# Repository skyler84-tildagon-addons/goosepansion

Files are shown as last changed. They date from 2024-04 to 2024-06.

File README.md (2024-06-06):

# Goosepansion

*Tildagon Badge Hexpansion by Skyler84*

The **Goosepansion** hexpansion is a capacitive touch addon for the Tildagon badge. Additionally it is designed to be reversible - it can be inserted in either orientation to alter the behaviour of the hexpansion!

## **IMPORTANT**

The hardware of the original Goosepansion had some issues with the active electronics. This is being investigated and a bodge fix will hopefully be released soon!

## Hardware

The goosepansion contains some active electronics that are supposed to allow it to be inserted in either orientation. This is achieved by switching two pairs of pass-fets acting as level shifters and *should* allow the I2C bus to work in either orientation. This had some issues in the original board which is being tested and updated.

### BOM

- 2 * [DMG6602SVTQ-7 complementary PN mosfet pair](https://www.mouser.co.uk/ProductDetail/Diodes-Incorporated/DMG6602SVTQ-7?qs=s5XU71A7K7%252BjMAi7Ml65qw%3D%3D)
- 2 * [DMN63D8LDW-7 dual n-channel mosfet](https://www.mouser.co.uk/ProductDetail/Diodes-Incorporated/DMN63D8LDW-7?qs=wo71MgyKIyE2w30D2buODQ%3D%3D)
- 1 * [M24C64-RDW6TP 8KB I2C EEPROM](https://www.mouser.co.uk/ProductDetail/STMicroelectronics/M24C64-RDW6TP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)
- 2 * 0603 LED
- 2 * current limiting resistors for LEDs
- 5 * 1k resistors
- 1 * 100k resistor

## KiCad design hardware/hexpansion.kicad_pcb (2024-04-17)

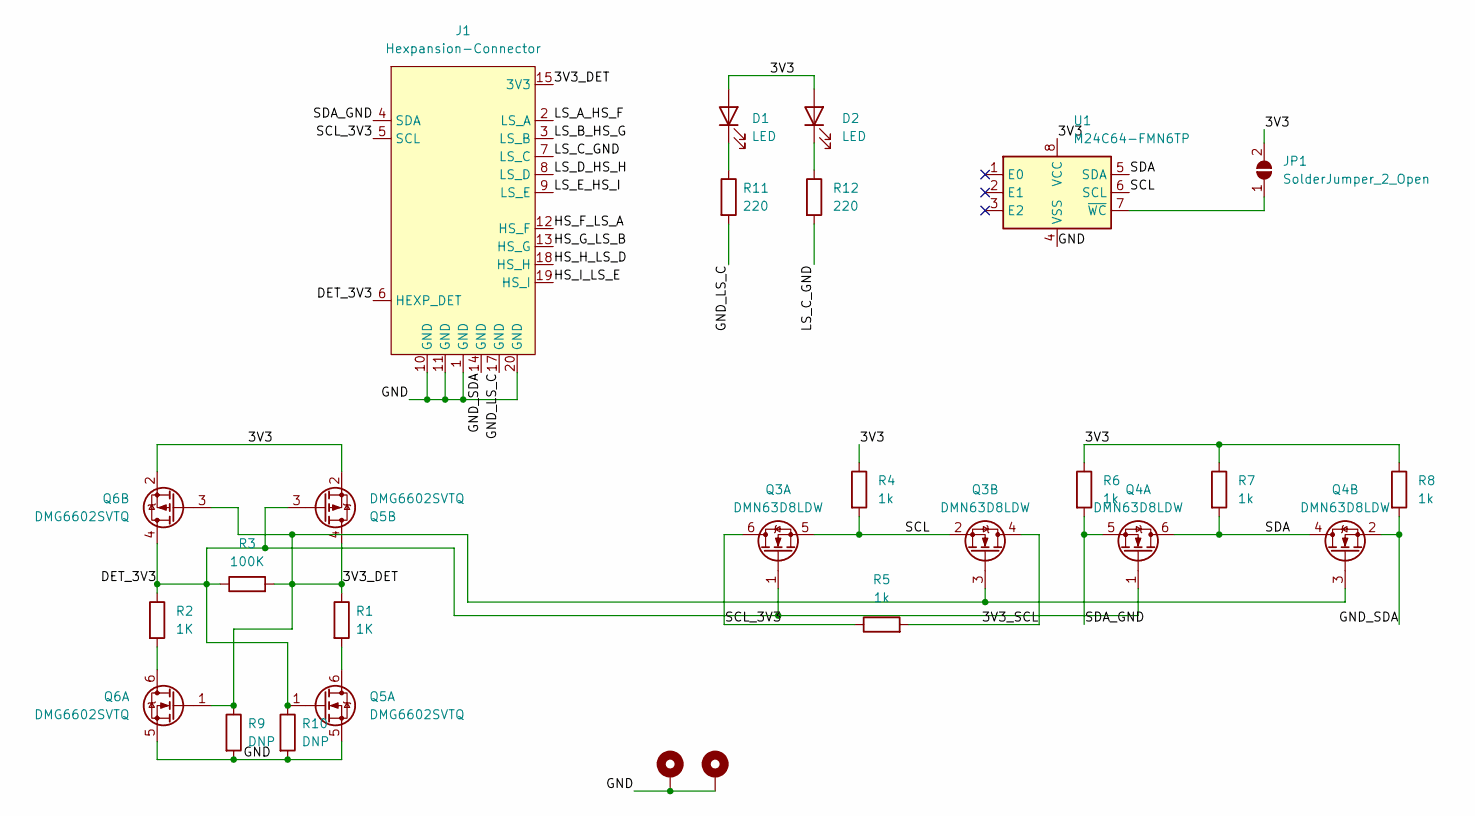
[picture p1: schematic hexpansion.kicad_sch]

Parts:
D1, D2: LED; LED_0603_1608Metric_Pad1.05x0.95mm_HandSolder
H1, H2: MountingHole_Pad; MountingHole_2.2mm_M2_Pad_Via
J1: Hexpansion-Connector; hexpansion-edge-connector
JP1: SolderJumper_2_Open; SolderJumper-2_P1.3mm_Open_RoundedPad1.0x1.5mm
Q3, Q4: DMN63D8LDW; SOT-363_SC-70-6
Q5, Q6: DMG6602SVTQ; TSOT-23-6
R1, R2: 1K; R_0603_1608Metric
R3: 100K; R_0603_1608Metric
R4, R5, R6, R7, R8: 1k; R_0603_1608Metric
R9, R10: DNP; R_0603_1608Metric
R11, R12: 220; R_0603_1608Metric
U1: M24C64-FMN6TP; SOIC-8_3.9x4.9mm_P1.27mm

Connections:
/3V3: D1.2 (A), D2.2 (A), JP1.2 (B), Q5.2 (S), Q6.2 (S), R4.1, R6.1, R7.1, R8.1, U1.8 (VCC)
/DET_3V3: J1.6 (HEXP_DET), Q3.1 (G), Q4.1 (G), Q5.1 (G), Q5.3 (G), Q6.4 (D), R2.1, R3.1, R10.1
/GND: H1.1, H2.1, J1.1 (GND), J1.10 (GND), J1.11 (GND), J1.20 (GND), Q5.5 (S), Q6.5 (S), R9.2, R10.2, U1.4 (VSS)
/GND_LS_C: J1.17 (GND), R11.2
/GND_SDA: J1.14 (GND), Q4.2 (S), R8.2
/HS_F_LS_A: J1.12 (HS_F)
/HS_G_LS_B: J1.13 (HS_G)
/HS_H_LS_D: J1.18 (HS_H)
/HS_I_LS_E: J1.19 (HS_I)
/LS_A_HS_F: J1.2 (LS_A)
/LS_B_HS_G: J1.3 (LS_B)
/LS_C_GND: J1.7 (LS_C), R12.2; also elsewhere on the board
/LS_D_HS_H: J1.8 (LS_D)
/LS_E_HS_I: J1.9 (LS_E)
/SCL: Q3.2 (S), Q3.5 (S), R4.2, U1.6 (SCL)
/SCL_3V3: J1.5 (SCL), Q3.6 (D), R5.1
/SDA: Q4.4 (D), Q4.6 (D), R7.2, U1.5 (SDA)
/SDA_GND: J1.4 (SDA), Q4.5 (S), R6.2
unnamed: D1.1 (K), R11.1
unnamed 19: D2.1 (K), R12.1; also elsewhere on the board
unnamed: JP1.1 (A), U1.7 (~WC)
unnamed: Q5.6 (D), R1.2
unnamed: Q6.6 (D), R2.2

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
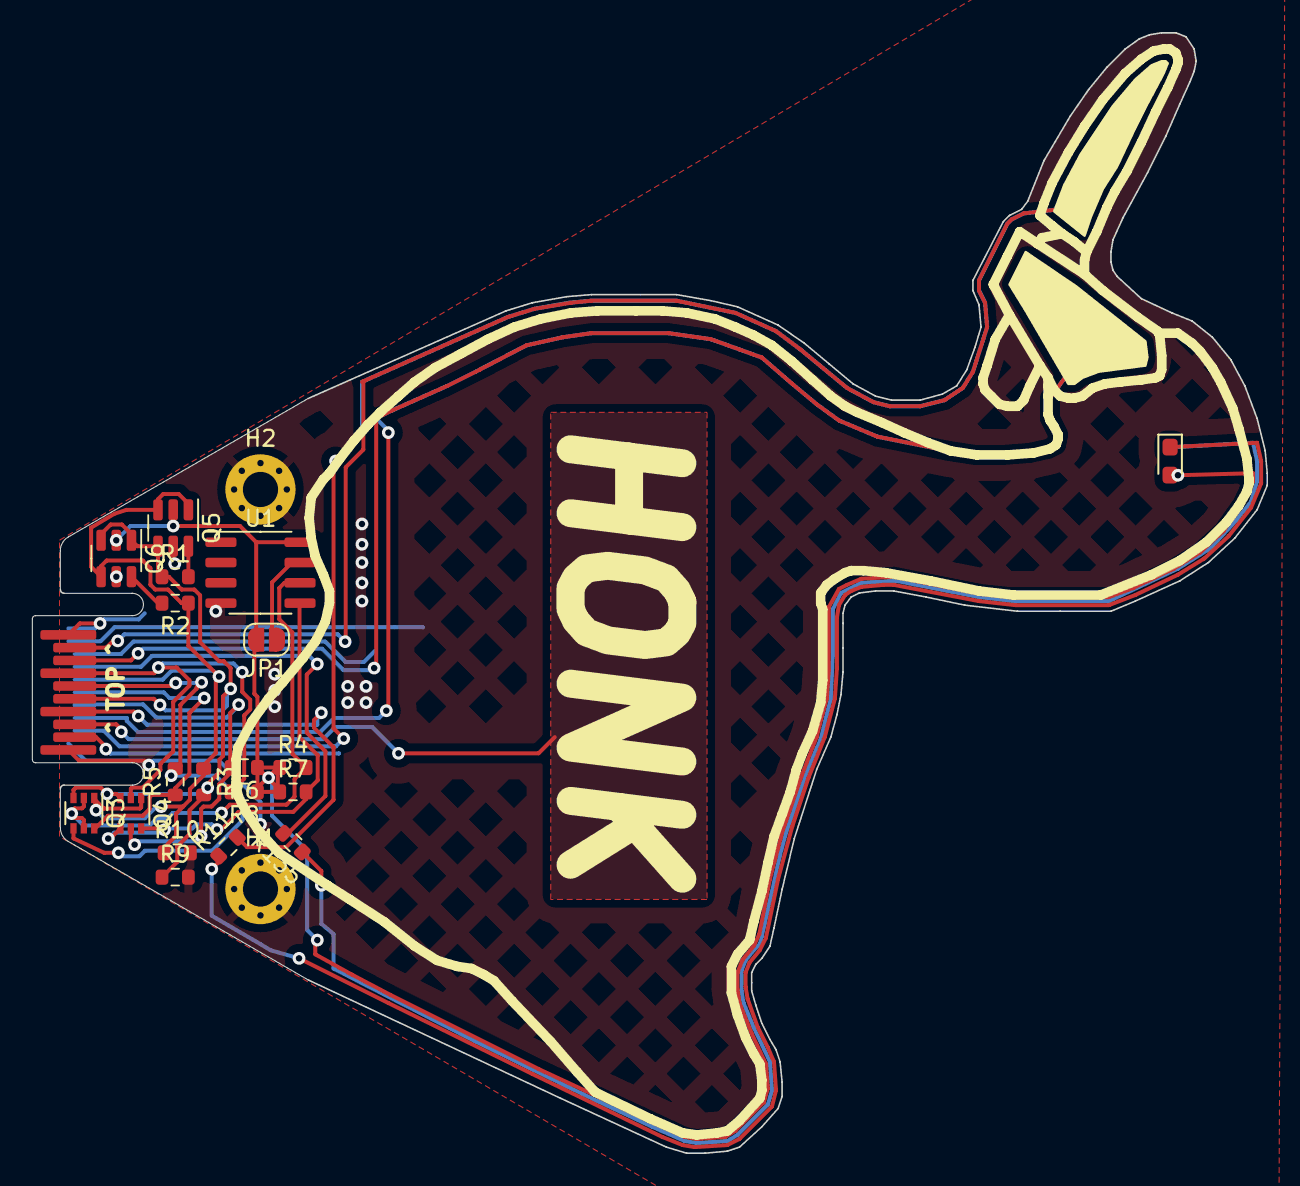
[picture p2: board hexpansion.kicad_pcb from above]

Board: 2 copper layers, 77.3 x 70.1 mm, 23 parts (1 on the bottom side), 17 nets.

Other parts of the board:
R135: 220; R_0603_1608Metric

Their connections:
/LS_C_GND: R135.2; also elsewhere on the board
unnamed 19: R135.1; also elsewhere on the board
